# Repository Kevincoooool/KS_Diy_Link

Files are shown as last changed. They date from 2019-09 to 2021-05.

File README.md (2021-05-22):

# Jlink_DIY
 * 个人DIY JLINK V9  高速SWD速度可达12000kHz
成品TB Link:[迷你JLink V9](https://item.taobao.com/item.htm?spm=a1z09.8149145.0.0.44cb53cdwAegGF&id=604502683248&_u=6kjj8627ebc)
* 推荐高速DAPLink&脱机烧录器：[高速DAP](https://item.taobao.com/item.htm?spm=a230r.1.14.40.7f906f07LiXFzK&id=610773587113)
*  串口波特率最高只支持**230400**
* DFU下载固件时需要将BOOT0短接3.3V同时RX引脚短接GND即可进入DFU模式
* 也可以用SWD接口直接把bootloader下载进去然后打开jlink commander 即可自动升级固件
* 如果提示了没license 就打开jlink commander 输入以下的sn  喜欢什么版本就输入什么sn
*  Exec SetSN=20281318    V9.2
*  Exec SetSN=20381318    V9.3
*  Exec SetSN=20481318    V9.4
*  Exec SetSN=20581318    V9.5
*  Exec SetSN=20681318    V9.6
*  Exec SetSN=20781318    V9.7
* 新版本的Jlink驱动要多加点内容，例如
* exec SetSN=20781318,0xCF2EF286

# Pic:<br> 
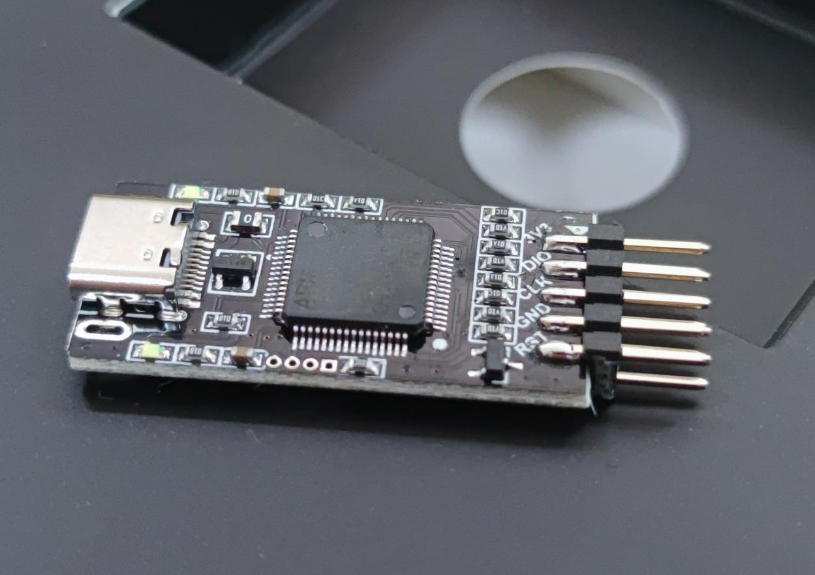
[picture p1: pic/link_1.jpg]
反面
 <br> 
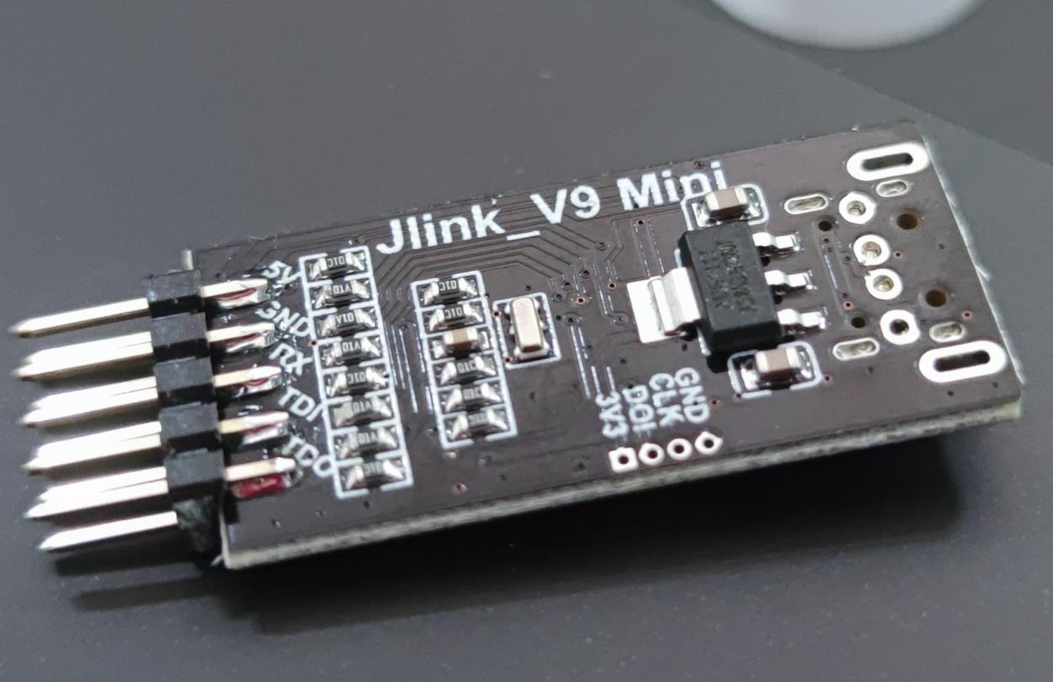
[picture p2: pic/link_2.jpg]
正面
 <br> 
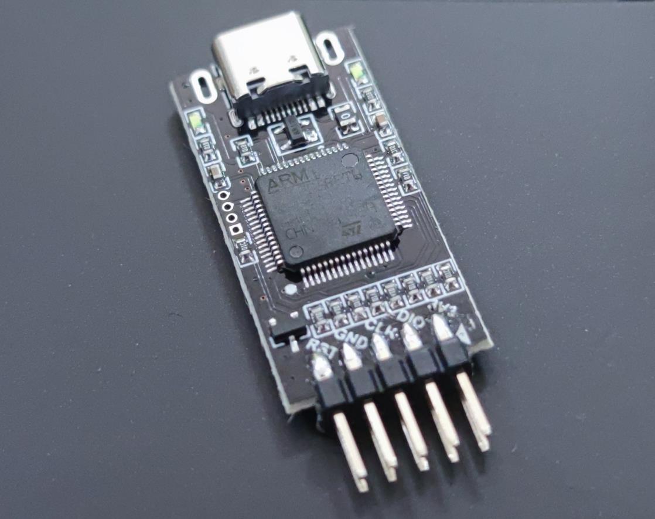
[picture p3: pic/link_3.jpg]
PCB
 <br>

> 另外强调一下，本仓库的项目是**GPL协议**，不支持任何形式的私自产品化（当然大家自己DIY是没有任何问题的，这里只是防止有人借我的名义坑大家）

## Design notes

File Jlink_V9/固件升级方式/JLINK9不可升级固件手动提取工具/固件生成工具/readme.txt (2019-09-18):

复制最新的JLinkARM.dll到这个目录，然后运行makev9fw.exe，完成之后J-Link V9 ALL.bin就是最新的固件了，这个固件需要写入mcu的0x08000000地址

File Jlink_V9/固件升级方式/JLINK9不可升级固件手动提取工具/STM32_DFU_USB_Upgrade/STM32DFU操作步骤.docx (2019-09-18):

第一步：下载了官方DFU软件后，安装软件包，安装完毕后代开这个软件的安装路径
需要再安装下STM32的USB驱动。路径如下（根据电脑系统选择安装X86还行x64）：


第二步：USB驱动安装上以后，用USB线将电脑和开发板连接，USB线接到开发板的这个USB口上，

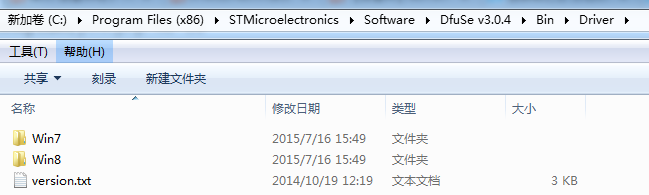
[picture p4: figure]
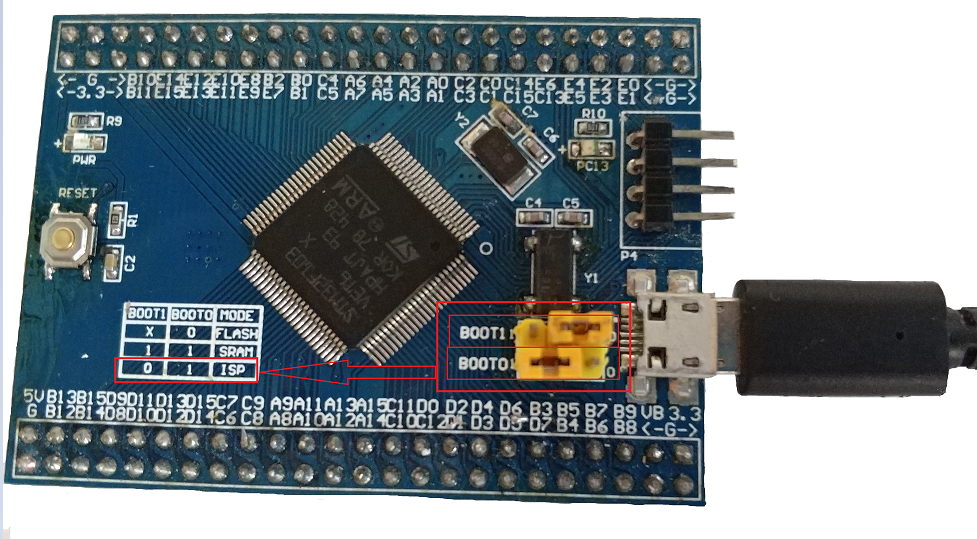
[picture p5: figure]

第三步：让开发板进入ISP模式，在电脑的资源管理器里面可以看到已经识别出USB

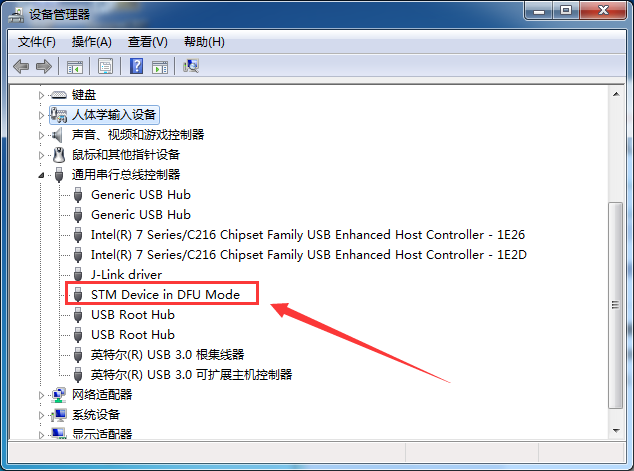
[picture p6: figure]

第4步：打开此路径下的这个软件：


选择这个选项


打开后后效果如下：

通过这个软件将bin文件或者S19文件转换成DFU文件格式文件的时候老是无法识别，弹出错误。

第5步：DfuFileMgr小软件里面有几个参数需要大家填好。
（1）Vendor ID，Product ID，和Version ID需要通过如下小软件进行获取：

打开软件后，参数在这里：


将其填写到DfuFileMgr里面：

（2）填写Target ID，这里填写0即可（填写其它数值的用途还没有研究）

（3）Target Name选项里面添写个名字即可，这里填写了个LED


（4）点击此选项，添加bin文件

（5）IAR和MDK工程生产bin文件
（6）添加bin文件：


（7）点击生产即可


特别注意，这个软件似乎有bug，不管你将生成的dfu文件保存到哪里，最终一定在安装目录的这个文件里面：


第6步：再次打开小软件DfuSeDemo，加载刚才的led.dfu。


第7步：提示加载完毕，并选择这个选项：


最后一步，点击Upgrade按钮：


重启开发板就可以运行了。

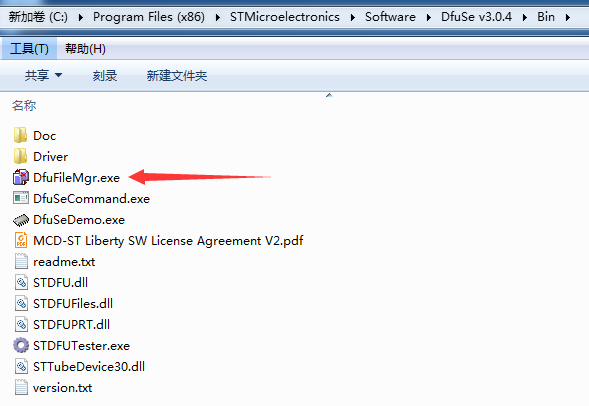
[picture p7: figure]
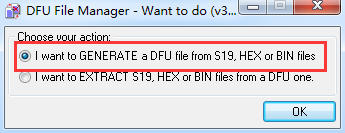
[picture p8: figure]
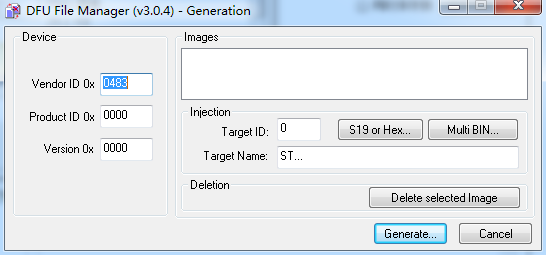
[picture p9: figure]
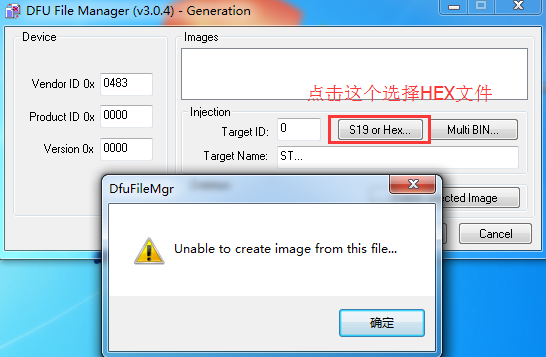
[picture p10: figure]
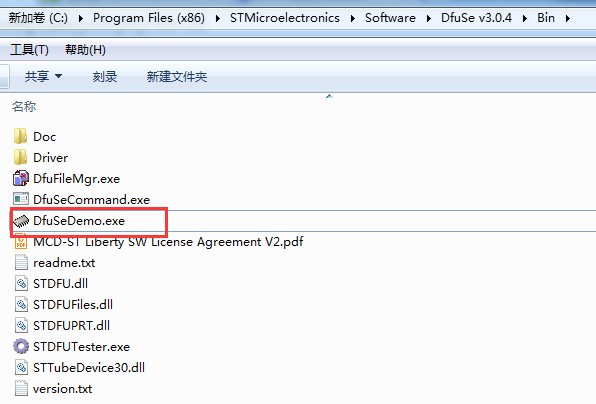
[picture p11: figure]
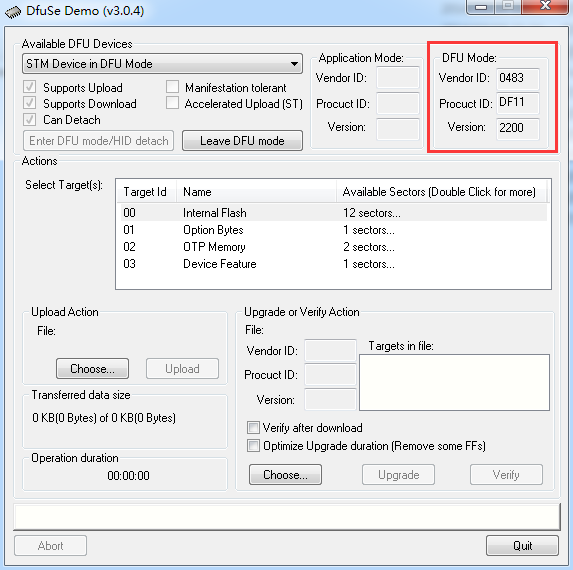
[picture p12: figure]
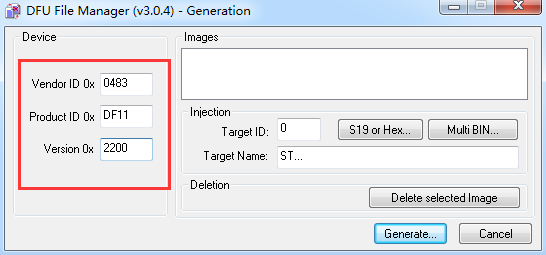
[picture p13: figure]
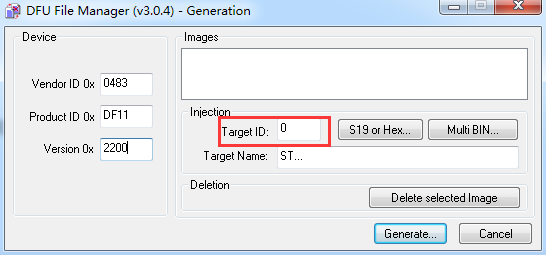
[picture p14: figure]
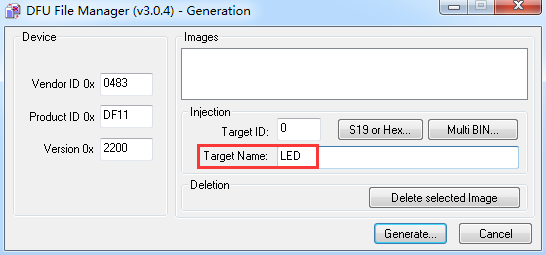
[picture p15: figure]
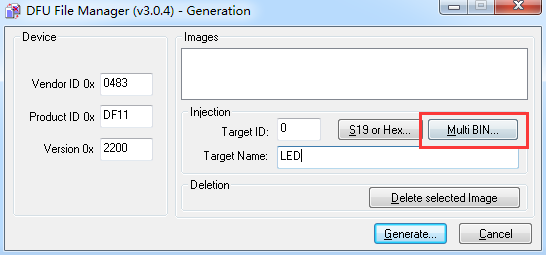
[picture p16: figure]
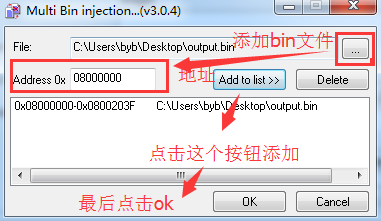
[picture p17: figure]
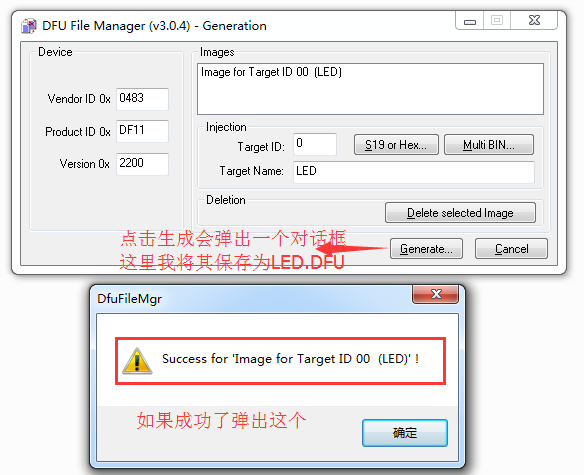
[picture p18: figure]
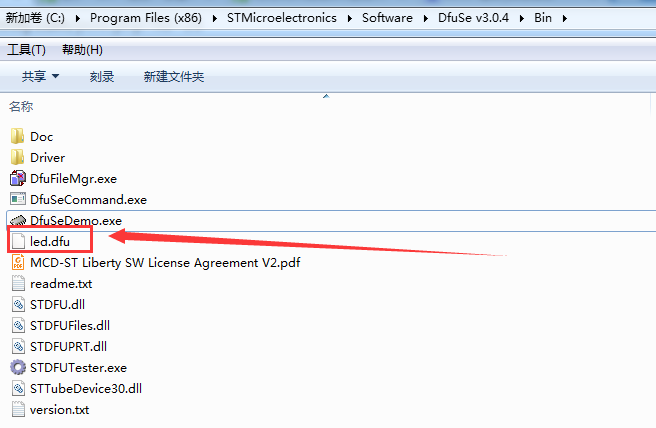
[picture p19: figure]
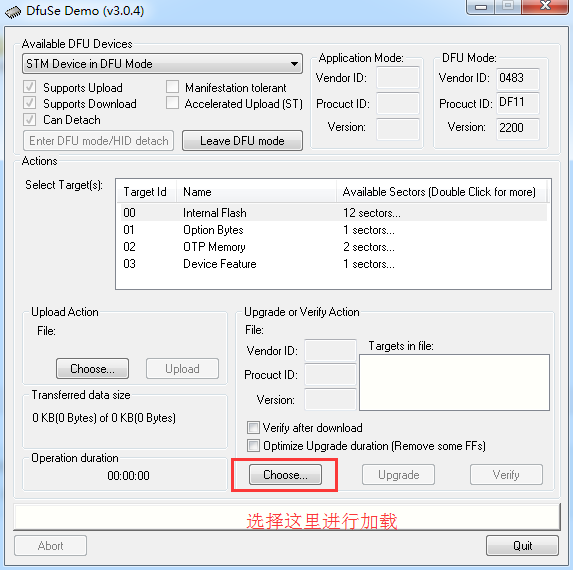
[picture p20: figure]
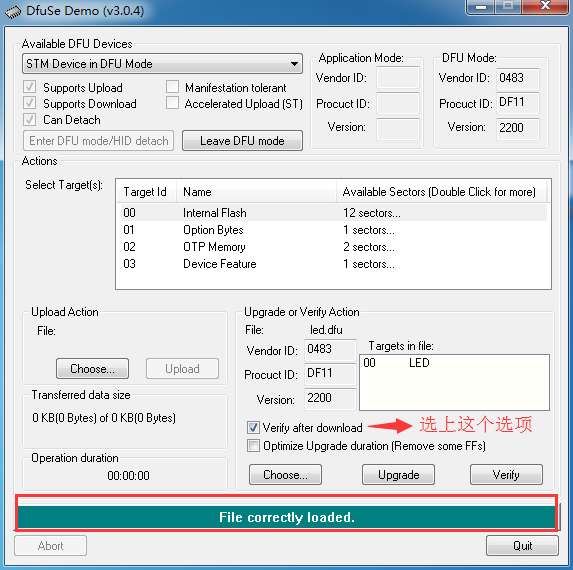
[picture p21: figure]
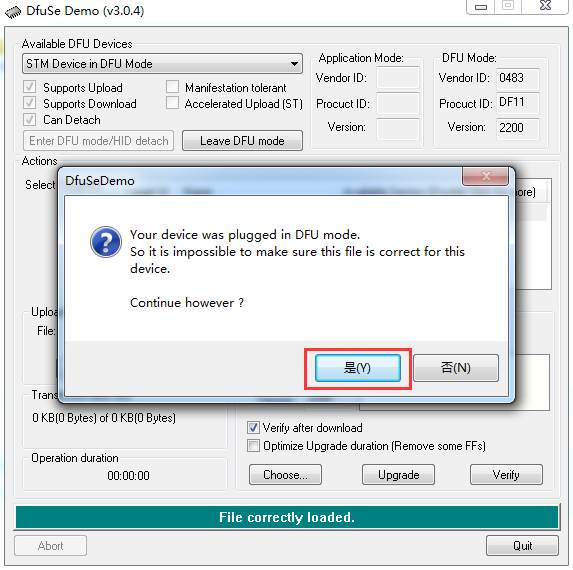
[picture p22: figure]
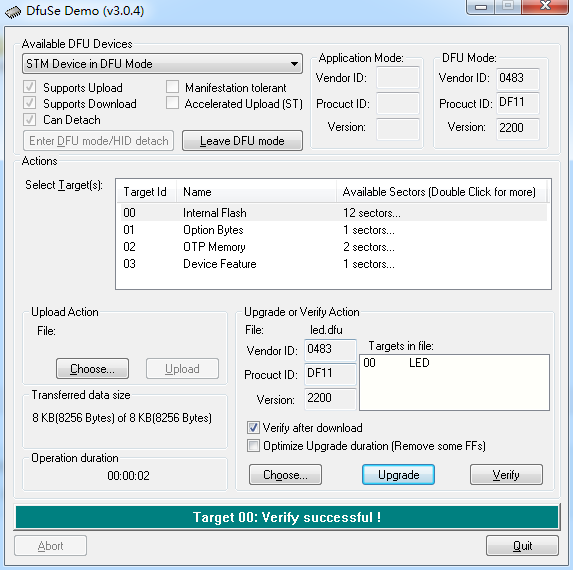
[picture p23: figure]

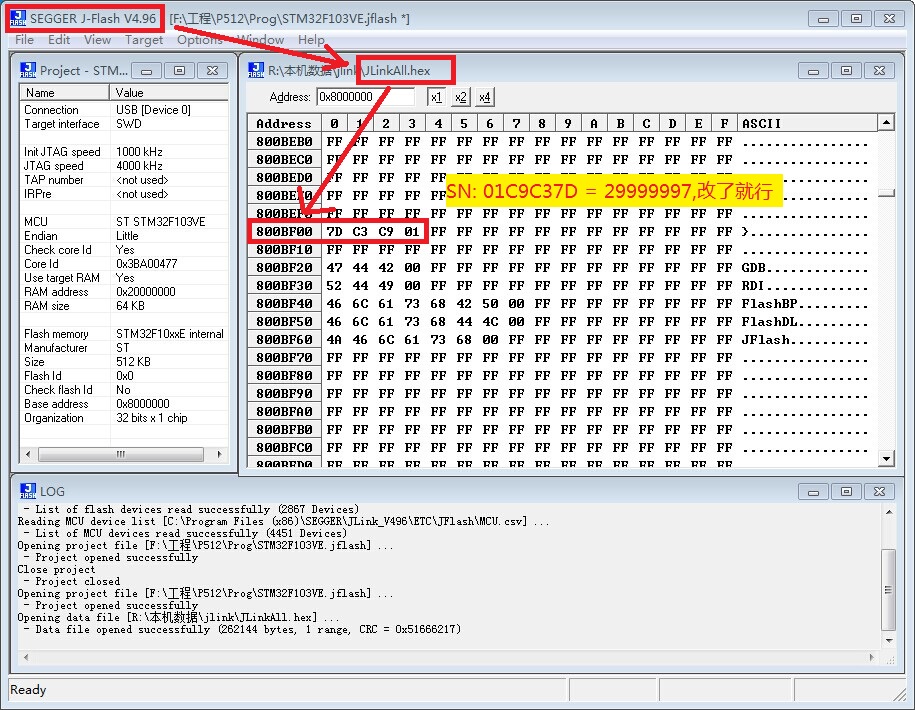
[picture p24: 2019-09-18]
Jlink_V9/固件升级方式/JLINK9不可升级固件手动提取工具/SN修改.jpg

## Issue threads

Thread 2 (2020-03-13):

Delivery problem

x893, 2020-03-13:
Hello,
thanks for this project !
I try to buy devices from Taobao but not dedlivery to my country. Possible buy from Aliexpress or other shop ?

Best regards
Mitek

majianjia, 2020-03-30:
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

It is nice to see you here!
Thanks for your initial works on RU forum and your post on your blog.
I can buy it from an agent (base in China) then send to your address.
If you need it, please contact me.

Kevincoooool, 2020-04-03:
Hi，I can give you the jlink by free，if you got a taobao account

---Original---
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

x893, 2020-04-03:
Thanks Kevin !
Yes, i have TaoBao account.
x89300

Kevincoooool, 2020-04-07:
I think you can learn about dotdotbuy...

x893, 2020-04-07:
OK, i'll learn.
I think some delivery problems with virus situation.
I design board with both microUSB and USB-A.

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

Thanks for your project !

x893, 2020-05-15:
Thanks Kevin !
i build JLinks with USB-A and microUSB (above) and both works fine.
Best wishes

Kevincoooool, 2020-07-08:
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

Hey,Did you find the JlinkOB firmware in JlinkARM.dll before? I have made a JLink OB SAM3U128 board now, but there is no bootloader, can you help me find it?

x893, 2020-07-08:
Hi, I never use SAM3 before. I see that some SAM3U128 firmwares presents in JLinkARM.dll but without bootloader. Before i havn't JLink bootloader (thank you for publish) i use system bootloader and upload firmware via ST FlashProgrammer. May be this way available for SAM3U.

Closed 2020-05-15.

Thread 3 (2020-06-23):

无法连接到STM32F030C8T6

johnzhy, 2020-06-23:
可以连接到STM32F1、F2，但是连接STM32F030C8T6的时候无法连接，MDK识别不到芯片，J-Flash连接的时候出现以下故障信息
Connecting ...
 - Connecting via USB to J-Link device 0
 - J-Link firmware: J-Link V9 compiled Dec 13 2019 11:14:50
 - Device "STM32F030C8" selected.
 - Target interface speed: 4000 kHz (Fixed)
 - VTarget = 3.306V
 - RESET (pin 15) high, but should be low. Please check target hardware.
 - RESET (pin 15) high, but should be low. Please check target hardware.
 - RESET (pin 15) high, but should be low. Please check target hardware.
 - RESET (pin 15) high, but should be low. Please check target hardware.
 - RESET (pin 15) high, but should be low. Please check target hardware.
 - RESET (pin 15) high, but should be low. Please check target hardware.
 - STM32 (connect): Can not attach to CPU. Trying connect under reset.
 - RESET (pin 15) high, but should be low. Please check target hardware.
 - RESET (pin 15) high, but should be low. Please check target hardware.
 - RESET (pin 15) high, but should be low. Please check target hardware.
 - STM32 (connect): Can not attach to CPU. Trying connect under reset.
 - RESET (pin 15) high, but should be low. Please check target hardware.
 - RESET (pin 15) high, but should be low. Please check target hardware.
 - ERROR: STM32: Connecting to CPU via connect under reset failed.
 - ERROR: Failed to connect.
Could not establish a connection to target.

Kevincoooool, 2020-06-23:
我用来给STM32F030F4P6是正常是下载的，检查一下连线？

johnzhy, 2020-06-23:
应该可以排除连线问题。
用diy-jlink可以给STM32F103RE、STM32F205RE正常下载程序，但是却无法识别STM32F030C8。
无法识别的这个STM32F030C8板子，可以被我手里别的jlink、STlink正常识别、下载、仿真。

Kevincoooool, 2020-06-23:
四根线都连上、3V3 DIO CLK GND   你的F0是不是低功耗带RST引脚的？现在的硬件RST引脚无法正常使用

johnzhy, 2020-06-23:
我手里正好有STM32F030F4P6，确实也可以正常连接。
STM32F030C8应该不是低功耗版本吧，和STM32F030F4P6一样的吧

Kevincoooool, 2020-06-23:
不是  要看C8T6的程序有没有进低功耗

johnzhy, 2020-06-23:
哦哦，明白你的意思了。那我把芯片程序擦除，看看能否连上就行吧

Kevincoooool, 2020-06-23:
是的，本身进了低功耗模式后必须要RST复位才能连接的

johnzhy, 2020-06-23:
刚刚试过，先用别的Jlink通过J-Flash擦除芯片，然后用DIY-Jlink还是连不上，错误信息还是一样的。

johnzhy, 2020-06-23:
对了，别的Jlink连接的时候也是四根线，没有连RST引脚

Kevincoooool, 2020-06-23:
那就不太清楚了- -我给每个F0下程序都没问题

johnzhy, 2020-06-23:
找到问题了，我对比了一下STM32F030C8的板子，这个板子的SWDIO和SWCLK引脚上都串联了一个100欧姆的电阻，其他可以连上的板子都没有，我把这两个电阻短路后就可以连上了。

Kevincoooool, 2020-06-23:
jlink上本身已经串联了一个100欧的电阻了

Closed 2020-06-23.

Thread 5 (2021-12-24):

F0/F1/F2都可以用，但是F4/F7不行

cxnaive, 2021-12-24:
测试了F0/F1/F2系列，但是尝试连接F4/F7的时候一直找不到CPU

JFlash V7.60b

Connecting ...
 - Connecting via USB to probe/ programmer device 0
 - Probe/ Programmer firmware: J-Link V9 compiled May  7 2021 16:26:12
 - Device "STM32F407IG" selected.
 - Target interface speed: 4000 kHz (Fixed)
 - VTarget = 3.282V
 - InitTarget() start
 - Can not attach to CPU. Trying connect under reset.
 - Connecting to CPU via connect under reset failed.
 - InitTarget() end
 - InitTarget() start
 - Can not attach to CPU. Trying connect under reset.
 - Connecting to CPU via connect under reset failed.
 - InitTarget() end
 - ERROR: Failed to connect.
Could not establish a connection to targe

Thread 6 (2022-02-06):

建议去除激活中添加RDDI特性的语句，会导致新版本JLink报clone警告

Oyami-Srk, 2022-02-06:
参考：[[原创]人人都可以拯救正版硬件受害者(Jlink提示Clone)
](https://bbs.pediy.com/thread-270744.htm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.)

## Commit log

2019-09-22 9-22
    增加RST
    [JLINK_V9_RST.PcbDoc, Jlink_V9.PcbDoc, Jlink_V9.PrjPcb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]
2020-03-02 重画PCB
    重新简化PCB，换AMS1117，增加复位三极管
    [JlinkV9_RST.PcbDoc, JlinkV9_RST.PrjPcb, JlinkV9_RST.SchDoc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]
2021-02-02 2-2 add photos
    [JLINK_OB_TYPEC.PcbDoc, JLINK_OB_TYPEC.PrjPcb, JLINK_OB_TYPEC.SchDoc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]
2021-05-22 更新CC脚 优化走线
    [JLINK_V9_RST.PcbDoc, JlinkV9_RST.PcbDoc, JlinkV9_RST.SchDoc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]
